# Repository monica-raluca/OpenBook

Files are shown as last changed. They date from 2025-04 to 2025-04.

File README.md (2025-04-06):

# 📚🌟 OpenBook 🌟📚
#### Birladeanu Raluca-Monica 335CA
> An infinite little library, your very own **pocket-sized story companion**.  Read a thousand books, live a thousand lives with OpenBook!~ 🌸
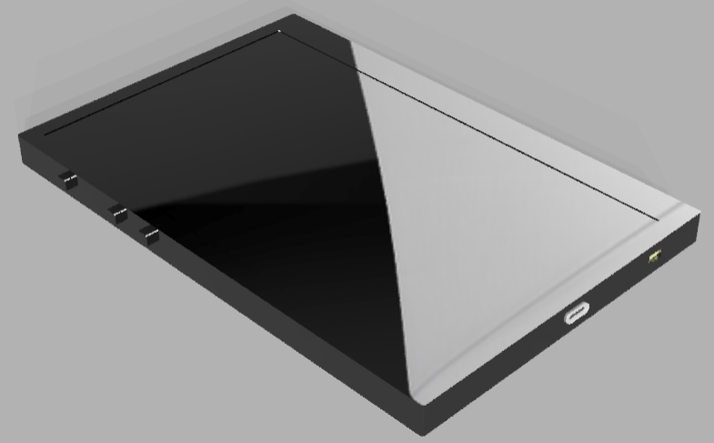
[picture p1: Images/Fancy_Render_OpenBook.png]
OpenBook Image

## Block Diagram
```mermaid
graph TD
  %% Center
  ESP[<span style='color:#e0ccff'><b>ESP32</b></span>]

  %% SPI Devices (Top)
  NOR[<span style='color:#ffcccc'>External NOR Flash</span>]
  EPD[<span style='color:#ffcccc'>E-Paper Display</span>]
  SD[<span style='color:#ffcccc'>SD Card</span>]

  NOR -->|SPI| ESP
  ESP -->|SPI| EPD
  SD -->|SPI| ESP

  %% I2C Devices (Bottom)
  RTC[<span style='color:#cce5ff'>RTC Module</span>]
  ENV[<span style='color:#cce5ff'>Environmental Sensor</span>]
  BCL[<span style='color:#cce5ff'>Battery Charge Level</span>]

  RTC -->|I2C| ESP
  ENV -->|I2C| ESP
  BCL -->|I2C| ESP

  %% Buttons (Left)
  BTN[<span style='color:#d4f4dd'>Buttons</span>]
  BTN --> ESP

  %% USB and Power (Right)
  USB[USB C Connector]
  CHG[Charging Controller]
  REG[Voltage Regulator]
  BATT[Battery]

  ESP -->|USB| USB
  USB --> CHG
  USB --> REG
  BATT --> CHG
  BATT --> REG

```
## Bill of Materials
|Component|Description|Purchase|Datasheet|
|---|---|---|---|
|EAGLE-LTSPICE_CC0402 | Capacitor | https://eu.mouser.com/ProductDetail/KEMET/C0402C475K8PACTU?qs=ulEaXIWI0c9ebKRT3r3htg%3D%3D | https://eu.mouser.com/datasheet/2/447/KEM_C1006_X5R_SMD-3316465.pdf
|ESP32_WROVER_EAGLE-LTSPICE_RR0402 | Resistor | https://eu.mouser.com/ProductDetail/Vishay-Beyschlag/MCS04020D9101BE000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  | https://www.vishay.com/docs/28700/mcx0x0xpre.pdf
|RCL_CPOL-EUCT3528 | Capacitor | https://eu.mouser.com/ProductDetail/Nichicon/LGN2W101MELA25?qs=Fe64Qgzkstf1zMszMsgRoA%3D%3D | https://eu.mouser.com/datasheet/2/293/e_lgn-3082370.pdf
|ADAFRUIT_LEDCHIP-LED0603 | LED | https://eu.mouser.com/ProductDetail/ams-OSRAM/KG-EELP41.22-PHRH-35-A8J8-20-R18?qs=ZcfC38r4Posajg8ZvCDQkg%3D%3D | https://eu.mouser.com/datasheet/2/588/KG_EELP41_22_EN-3572852.pdf
|CPH3225A | Capacitor | https://eu.mouser.com/ProductDetail/Seiko-Semiconductors/CPH3225A?qs=3etwrb1wR%252BhUOph6lAO7eg%3D%3D | https://eu.mouser.com/datasheet/2/360/Seiko_Instruments_MicroBattery_E_20230330_2024Jan_-3561061.pdf
|ESP32_WROVER_SPARKFUN-DISCRETESEMI_MOSFET_PCH-DMG2305UX-7 | Transistor | https://eu.mouser.com/ProductDetail/Diodes-Incorporated/DMG2305UX-7?qs=L1DZKBg7t5F%2FNBHrjfxC%252Bg%3D%3D | https://www.diodes.com/assets/Datasheets/DMG2305UX.pdf
|ESP32_WROVER_AVX---SD0805S020S1R0_AVX_SD0805S020S1R0_0_0AVX_SD0805S020S1R0_0_0 | Diode | https://eu.mouser.com/ProductDetail/ROHM-Semiconductor/SCS310AMC7G?qs=iLKYxzqNS75xiccEgNnX2g%3D%3D | https://fscdn.rohm.com/en/products/databook/datasheet/discrete/sic/sbd/scs310am-e.pdf
|SI1308EDL-T1-GE3 | Transistor | https://eu.mouser.com/ProductDetail/Vishay-Semiconductors/SI1308EDL-T1-GE3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 | https://www.vishay.com/docs/63399/si1308edl.pdf
|ESP32C6_VARISTORCN1812 | Varistor | https://eu.mouser.com/ProductDetail/Schurter/PFMF.050.2?qs=1auRipcfynCums5v1iucSA%3D%3D | https://eu.mouser.com/datasheet/2/358/typ_PFMF-1275918.pdf
|ESP32_WROVER_BME680_BME680 | Integrated Environmental Unit | https://eu.mouser.com/ProductDetail/M5Stack/U001-C?qs=e8oIoAS2J1R2mB7ZY1%252BSZg%3D%3D | https://docs.m5stack.com/en/unit/envIII
|ESP32-C6-WROOM-1-N8 | MicroController | https://eu.mouser.com/ProductDetail/Espressif-Systems/ESP32-C6?qs=Imq1NPwxi75noDtUpuVuWw%3D%3D | https://eu.mouser.com/datasheet/2/891/esp32_c6_datasheet_en-3304070.pdf
| 744043680IND_4828-WE-TPC_WRE | Inductor | https://eu.mouser.com/ProductDetail/Wurth-Elektronik/744043680?qs=PGXP4M47uW6VkZq%252BkzjrHA%3D%3D | https://www.we-online.com/components/products/datasheet/744043680.pdf
|SI1308EDL-T1-GE3 | Transistor | https://eu.mouser.com/ProductDetail/Vishay-Semiconductors/SI1308EDL-T1-GE3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 | https://www.vishay.com/docs/63399/si1308edl.pdf
| BD5229G-TR | Voltage Detector | https://eu.mouser.com/ProductDetail/ROHM-Semiconductor/BD5229G-TR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 | https://fscdn.rohm.com/en/products/databook/datasheet/ic/power/voltage_detector/bd52xxg-e.pdf
|DS3231SN# | RTC Module | https://eu.mouser.com/ProductDetail/Analog-Devices-Maxim-Integrated/DS3231SN?qs=1eQvB6Dk1vhUlr8%2FOrV0Fw%3D%3D | https://eu.mouser.com/datasheet/2/609/DS3231-3421123.pdf
|USBLC6-2SC6Y | ESD Protection | https://eu.mouser.com/ProductDetail/STMicroelectronics/USBLC6-2SC6Y?qs=gNDSiZmRJS%2FOgDexvXkdow%3D%3D | https://eu.mouser.com/datasheet/2/389/usblc6_2sc6y-1852505.pdf
|W25Q512JVEIQ | Flash Memory | https://eu.mouser.com/ProductDetail/Winbond/W25Q512JVEIQ?qs=l7cgNqFNU1jw6svr3at6tA%3D%3D | https://eu.mouser.com/datasheet/2/949/Winbond_W25Q512JV_Datasheet-3240039.pdf
|SAMACSYS_PARTS_USB4110-GF-A | USB Connector | https://eu.mouser.com/ProductDetail/GCT/USB4110-GF-A?qs=KUoIvG%2F9IlYiZvIXQjyJeA%3D%3D | https://eu.mouser.com/datasheet/2/837/GCT_USB4110_Product_Drawing___20k_cycles-3455479.pdf
|FH34SRJ | E-Paper Display Header | https://eu.mouser.com/ProductDetail/Hirose-Connector/FH34SRJ-7S-0.5SH50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 | https://eu.mouser.com/datasheet/2/185/FH34SRJ_7S_0_5SH_50__CL0580_1200_0_50_2DDrawing_00-1615127.pdf
|MAX17048G+T10 | Battery Management | https://eu.mouser.com/ProductDetail/Analog-Devices-Maxim-Integrated/MAX17048G%2bT10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 | https://eu.mouser.com/datasheet/2/609/MAX17048_MAX17049-3469099.pdf
|MCP73831 | Battery Controller | https://eu.mouser.com/ProductDetail/Microchip-Technology/MCP73831T-2ATI-MC?qs=yUQqVecv4qs9k7ug0bEXiw%3D%3D | https://eu.mouser.com/datasheet/2/268/MCP73831_Family_Data_Sheet_DS20001984H-3441711.pdf
|112A-TAAR-R03_ATTEND | SD Card Mount | https://store.comet.srl.ro/Catalogue/Product/43497/ | https://store.comet.srl.ro/Catalogue/Product/43497/
|XC6220A331MR-G | LDO Voltage Regulator | https://eu.mouser.com/ProductDetail/Torex-Semiconductor/XC6220A331MR-G?qs=AsjdqWjXhJ8ZSWznL1J0gg%3D%3D | https://eu.mouser.com/datasheet/2/760/xc6220-3371556.pdf

## Hardware components
- ESP32-C6-WROOM-1-N8 Microcontroller

### Communication interfaces

| Communication interface | Connected Components |
|---|---|
| I2C | RTC, BME688, Battery Level |
| SPI | SD Card, E-Paper Display, NOR Flash |
| USB | USB C Connector / Power |

### ESP32-C6-WROOM-1-N8 Pin Mapping

| ESP32 Pin | Signal | Purpose |
|---|---|---|
| IO0 | INT_RTC | RTC communication |
| IO1 | 32KHZ | RTC communication |
| IO2 | MISO | SD Card, NOR Flash |
| IO3 | EPD_BUSY | EPD status |
| IO4 | SS_SD | SD Card |
| IO5 | EPD_DC | EPD Data/Command |
| IO6 | SCK  | BME688, SD Card, NOR Flash |
| IO7 | MOSI | SD Card, NOR Flash, EPD |
| IO8 | GPIO8 | SD card select |
| IO9 | IO/BOOT | Boot button |
| IO10 | EPD_CS | EPD chip select|
| IO11 | FLASH_CS | NOR Flash chip select |
| IO12 | USB_D-| USB communication |
| IO13 | USB_D+ | USB communication |
| IO15 | IO/CHANGE | Button change |
| IO16 | TX | Transmit |
| IO17 | RX | Receive |
| IO18 | RTC_RST | RTC reset |
| IO19 | I2C_PW | BME688 power management |
| IO20 | EPD_3V3_C | EPD |
| IO21 | SDA | RTC, BME688, Battery Level (I2C data) |
| IO22 | SCL | RTC, BME688, Battery Level (I2C clock) |
| IO23 | EPD_RST | EPD reset |

- Real-Time Clock Module (RTC)
  - A DS3231SN RTC module
  - It communicates through I2C with the microcontroller
  - Pin connections:
      - SCL -> IO22
      - SDA -> IO21
      - RTC_RST -> IO18
      - 32KHZ -> IO1
      - INT_RTC -> IO0
- SD Card
  - It communicates through SPI
  - Pin connections:
    - MISO - IO2
    - SCK - IO6
    - MOSI - IO7
    - SS_SD - IO4
- E-Paper Display (EPD)
  - It communicates through SPI
  - Pin connections:
    - EPD_CS -> IO10
    - EPD_DC -> IO5
    - EPD_RST -> IO23
    - EPD_BUSY -> IO3
    - MOSI, SCK -> shared with SD
- Environmental Sensor
  - BME688 sensor
  - It communicates through I2C
  - Pin connections:
      - SCL -> IO22
      - SDA -> IO21
- Li-Po Battery Charging Controller
  - Battery Charge Level
    - It communicates through I2C
    - Pin connections:
        - SCL -> IO22
        - SDA -> IO21
- LDO Voltage Regulator
  - Lowers the 5V to 3.3V for the microcontroller and the attached modules
- SPI ESD Protection Lines
- NOR Flash 64MB
  - It communicates through SPI
  - Pin connections:
    - FLASH_CS -> IO11
    - SCK, MOSI, MISO
- USB
  - USB_D- -> IO12
  - USB_D+ -> IO13
- Buttons for user input
  - RESET -> EN
  - IO/BOOT -> IO9
  - IO/CHANGE -> IO15
- Qwiic / Stemma QT Connector
  - It communicates through I2C
  - SCL, SDA

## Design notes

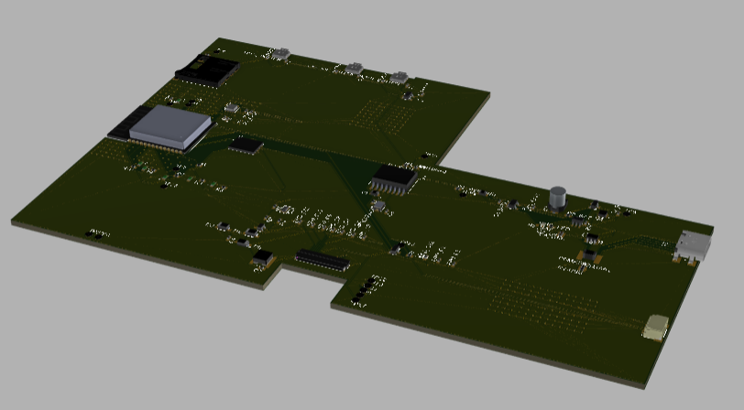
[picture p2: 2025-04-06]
Images/Side_view_Board.png

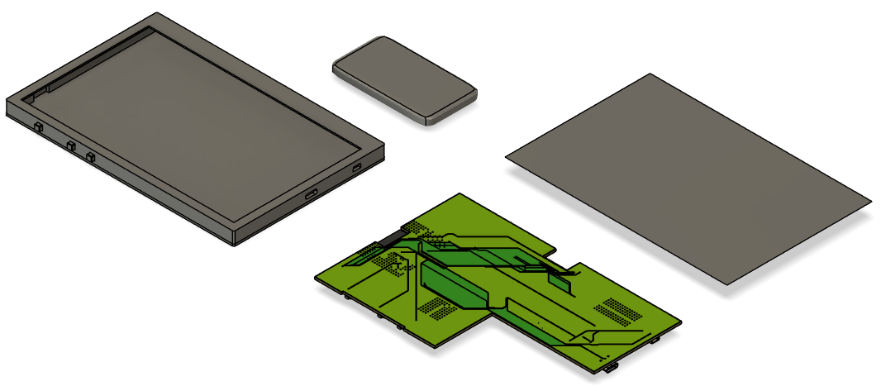
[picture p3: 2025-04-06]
Images/Animation_View_OpenBook.png

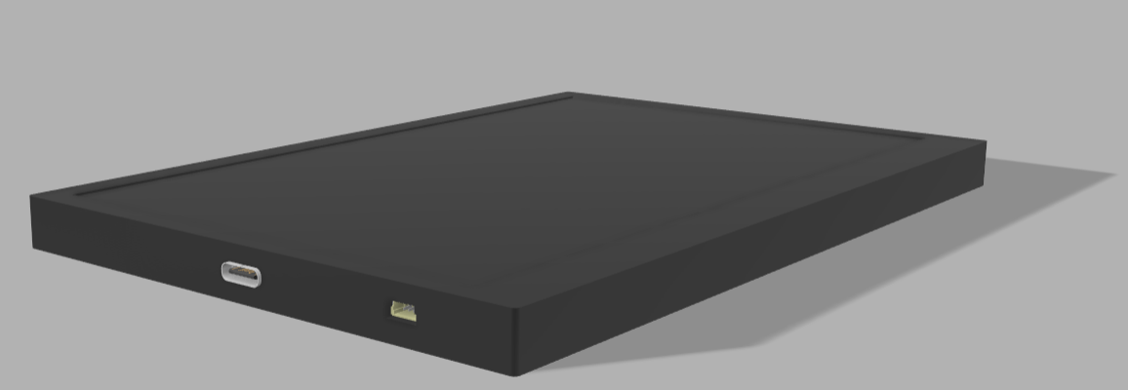
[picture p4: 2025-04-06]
Images/Side_view_OpenBook.png

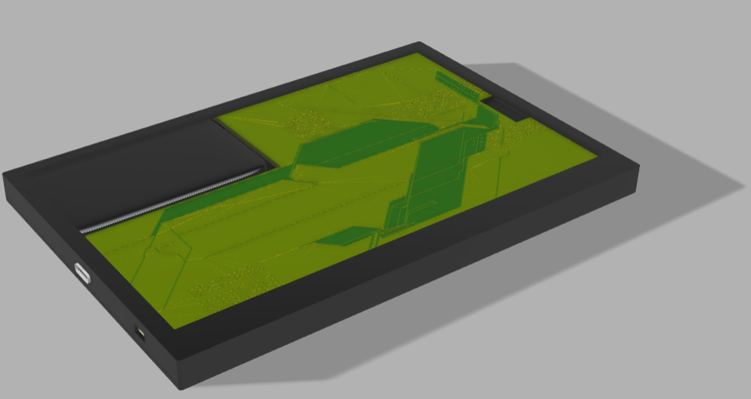
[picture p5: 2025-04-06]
Images/Interior_OpenBook.png

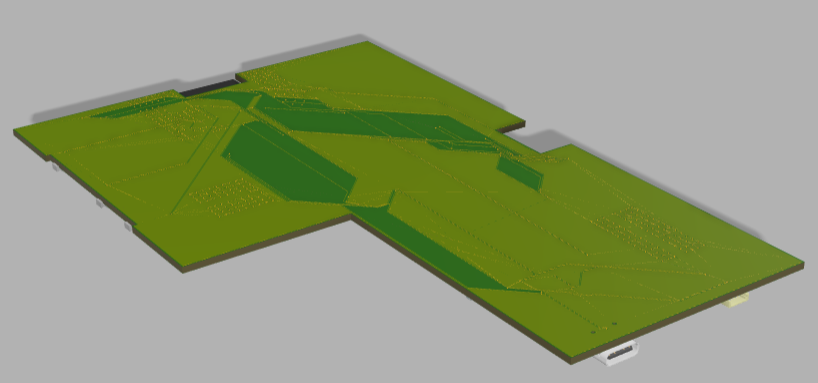
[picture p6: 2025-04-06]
Images/Second_Side_Board.png

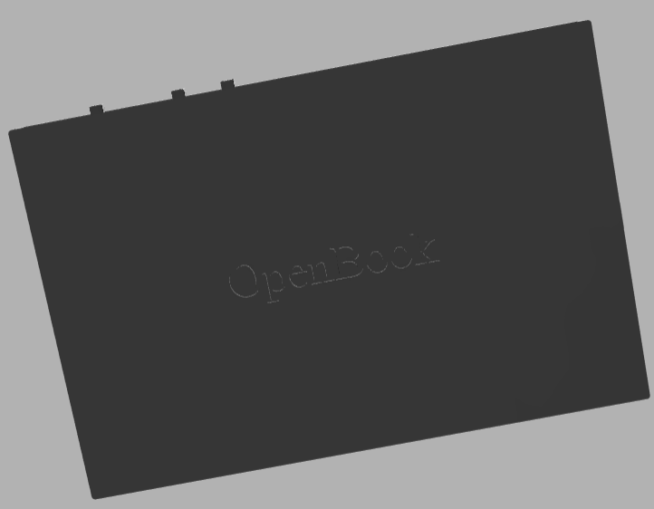
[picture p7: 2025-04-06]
Images/Back_view_OpenBook.png

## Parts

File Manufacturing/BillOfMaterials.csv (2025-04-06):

Qty | Value | Device | Package | Parts | Description | ARROW_PART_NUMBER | ARROW_PRICE-STOCK | AVAILABILITY | CHECK_PRICES | COPYRIGHT | DESCRIPTION | HEIGHT | MANUFACTURER_NAME | MANUFACTURER_PART_NUMBER | MF | MFR_NAME | MOUSER_PART_NUMBER | MOUSER_PRICE-STOCK | MOUSER_TESTING_PART_NUMBER | MOUSER_TESTING_PRICE-STOCK | MP | PACKAGE | POPULARITY | PRICE | PROD_ID | PURCHASE-URL | SNAPEDA_LINK | SPICEPREFIX | VALUE
1 |  | ADAFRUIT_LEDCHIP-LED0603 | ADAFRUIT_CHIP-LED0603 | CHG_LED | LED
1 |  | SJ | SJ | SJ1 | SMD solder JUMPER |  |  |  |  |  |  |  |  |  |  |  |  |  |  |  |  |  | 3
1 | 0.1uF/50V | EAGLE-LTSPICE_CC0402 | EAGLE-LTSPICE_C0402 | EPD_C5 | CAPACITOR, European symbol
1 | 0.47 | ESP32_WROVER_EAGLE-LTSPICE_RR0402 | ESP32_WROVER_EAGLE-LTSPICE_R0402 | R3 | RESISTOR, European symbol
1 | 100K | ESP32_WROVER_EAGLE-LTSPICE_RR0402 | ESP32_WROVER_EAGLE-LTSPICE_R0402 | R1_PWRUSB | RESISTOR, European symbol
8 | 100nF | EAGLE-LTSPICE_CC0402 | EAGLE-LTSPICE_C0402 | C1, C2, C4_USB, C6, C8, C9, C10, C_DELAY | CAPACITOR, European symbol
1 | 100uF | RCL_CPOL-EUCT3528 | RCL_CT3528 | C3 | POLARIZED CAPACITOR, European symbol |  |  |  |  |  |  |  |  |  |  |  |  |  |  |  |  |  | 0 |  |  |  |  | C
16 | 10K | ESP32_WROVER_EAGLE-LTSPICE_RR0402 | ESP32_WROVER_EAGLE-LTSPICE_R0402 | R1, R1_PINH, R1_PINH1, R2_PINH, R2_PINH1, R4, R5, R6, R7, R8, R9, R10, R_BOOT, R_CHANGE, R_CL1, R_RESET | RESISTOR, European symbol
1 | 10uF | EAGLE-LTSPICE_CC0402 | EAGLE-LTSPICE_C0402 | C7 | CAPACITOR, European symbol
1 | 112A-TAAR-R03_ATTEND | 112A-TAAR-R03_ATTEND | 112ATAARR03ATTEND | J4 | Micro SD Card Socket, Push-Push Type, Top Mount, SMT, H=1.83mm, 10u |  |  |  |  |  | Micro SD Card Socket | Push-Push Type | Top Mount | SMT | H=1.83mm | 10u | 1.9mm | ATTEND | 112A-TAAR-R03 ATTEND
1 | 15 | ESP32_WROVER_EAGLE-LTSPICE_RR0402 | ESP32_WROVER_EAGLE-LTSPICE_R0402 | R_CAPACITOR | RESISTOR, European symbol
1 | 1uF | EAGLE-LTSPICE_CC0402 | EAGLE-LTSPICE_C0402 | C5 | CAPACITOR, European symbol
9 | 1uF/50V | EAGLE-LTSPICE_CC0402 | EAGLE-LTSPICE_C0402 | EPD_C1, EPD_C2, EPD_C6, EPD_C7, EPD_C8, EPD_C9, EPD_C10, EPD_C11, EPD_C12 | CAPACITOR, European symbol
1 | 2.2 | ESP32_WROVER_EAGLE-LTSPICE_RR0402 | ESP32_WROVER_EAGLE-LTSPICE_R0402 | R2 | RESISTOR, European symbol
1 | 200 | ESP32_WROVER_EAGLE-LTSPICE_RR0402 | ESP32_WROVER_EAGLE-LTSPICE_R0402 | R1_BAT | RESISTOR, European symbol
2 | 20V/4.2A/52mO/1.4W | ESP32_WROVER_SPARKFUN-DISCRETESEMI_MOSFET_PCH-DMG2305UX-7 | ESP32_WROVER_SPARKFUN-DISCRETESEMI_SOT23-3 | Q1, Q2 | P-channel MOSFETs
1 | 2K | ESP32_WROVER_EAGLE-LTSPICE_RR0402 | ESP32_WROVER_EAGLE-LTSPICE_R0402 | R2_BAT | RESISTOR, European symbol
5 | 4.7uF | EAGLE-LTSPICE_CC0402 | EAGLE-LTSPICE_C0402 | C1_BAT, C1_BAT1, C1_BAT2, C2_BAT, C5_USB | CAPACITOR, European symbol
1 | 4.7uF/25V | EAGLE-LTSPICE_CC0402 | EAGLE-LTSPICE_C0402 | C4 | CAPACITOR, European symbol
2 | 5k1 | ESP32_WROVER_EAGLE-LTSPICE_RR0402 | ESP32_WROVER_EAGLE-LTSPICE_R0402 | R2-USB, R2-USB1 | RESISTOR, European symbol
1 | 68uH | 744043680IND_4828-WE-TPC_WRE | IND_4828-WE-TPC_WRE | L1 |  |  |  |  |  | Copyright (C) 2024 Ultra Librarian. All rights reserved. |  |  |  | 744043680 |  | Wurth Electronics
1 | BD5229G-TR | BD5229G-TR | SOT95P280X125-5N | IC1 | Voltage Detector with Adjustable Delay Time: CMOS processes are utilized to develop high precision, low current consumption CMOS reset ICs that allow arbitrary setting of the delay time. The extensive lineup includes both Nch Open Drain and CMOS output types in a wide range of detection voltages (from 2.3V to 6.0V, in 0.1V steps), enabling selection of the ideal solution based on customer requirements. In addition, the entire series is of course both lead-free and RoHS-compliant. |  |  |  |  |  | Voltage Detector with Adjustable Delay Time: CMOS processes are utilized to develop high precision | low current consumption CMOS reset ICs that allow arbitrary setting of the delay time. The extensive lineup includes both Nch Open Drain and CMOS output types in a wide range of detection voltages (from 2.3V to 6.0V | in 0.1V steps) | enabling selection of the ideal solution based on customer requirements. In addition | the entire series is of course both lead-free and RoHS-compliant. | 1.25mm | ROHM Semiconductor | BD5229G-TR |  |  | 755-BD5229G-TR | https://www.mouser.co.uk/ProductDetail/ROHM-Semiconductor/BD5229G-TR?qs=4kLU8WoGk0vvnhrrYwdszw%3D%3D
1 | BME688 | ESP32_WROVER_BME680_BME680 | ESP32_WROVER_BME680_PSON80P300X300X100-8N | SENSOR2 | Integrated Environmental Unit |  |  | Unavailable |  |  | Integrated Environmental Unit |  |  |  | Bosch Sensortec |  |  |  |  |  | BME680 | LGA-8 Bosch Tools |  | None
3 | BUTTON_CUSYOMV1MYBUTTON | BUTTON_CUSYOMV1MYBUTTON | MYBUTTON | BOOT_BUTTON, CHANGE_BUTTON, RESET_BUTTON
1 | CPH3225A | CPH3225A | CAPCP3225X100N | C10_SUPERCAP | Cap 0.011F 3.3V 1210 Flat Check availability |  |  | Not in stock | https://www.snapeda.com/parts/CPH3225A/Seiko+Instruments/view-part/?ref=eda |  | 11 mF (EDLC) Supercapacitor 3.3 V 1210 (3225 Metric) - - |  |  |  | Seiko Instruments |  |  |  |  |  | CPH3225A | 1210 Seiko |  | None |  | https://www.snapeda.com/api/url_track_click_mouser/?unipart_id=562593&manufacturer=Seiko Instruments&part_name=CPH3225A&search_term=None | https://www.snapeda.com/parts/CPH3225A/Seiko+Instruments/view-part/?ref=snap
1 | DS3231SN# | DS3231SN# | SOIC127P1032X265-16N | U3 | Real Time Clock Serial 16-Pin SOIC W T/R Check availability |  |  | In Stock | https://www.snapeda.com/parts/DS3231SN%23/Analog+Devices/view-part/?ref=eda |  | Extremely Accurate I²C-Integrated RTC/TCXO/Crystal |  |  |  | Analog Devices |  |  |  |  |  | DS3231SN# | SOIC-16 Maxim |  | None |  | https://www.snapeda.com/api/url_track_click_mouser/?unipart_id=99048&manufacturer=Analog Devices&part_name=DS3231SN#&search_term=None | https://www.snapeda.com/parts/DS3231SN%23/Analog+Devices/view-part/?ref=snap
1 | ESP32-C6-WROOM-1-N8 | ESP32-C6-WROOM-1-N8 | XCVR_ESP32-C6-WROOM-1-N8 | U2 | Check availability |  |  | In Stock | https://www.snapeda.com/parts/ESP32-C6-WROOM-1-N8/Espressif+Systems/view-part/?ref=eda |  | Multiprotocol Modules ESP32-C6 module | Wi-Fi 6 in 2.4 GHz band | Bluetooth 5 | Zigbee 3.0 and Thread. ESP34-WROOM Compatible - ENGINEERING SAMPLE |  |  |  | Espressif Systems |  |  |  |  |  | ESP32-C6-WROOM-1-N8 | None |  | None
1 | ESP32C6_VARISTORCN1812 | ESP32C6_VARISTORCN1812 | ESP32C6_VARISTOR_CT/CN1812 | PFMF.050.1 | VARISTOR |  |  |  |  |  |  |  |  |  |  |  |  |  |  |  |  |  | 0
2 | ESP32_WROVER_AVX---SD0805S020S1R0_AVX_SD0805S020S1R0_0_0AVX_SD0805S020S1R0_0_0 | ESP32_WROVER_AVX---SD0805S020S1R0_AVX_SD0805S020S1R0_0_0AVX_SD0805S020S1R0_0_0 | ESP32_WROVER_AVX---SD0805S020S1R0_AVX_SD0805S020S1R0_0 | D2, D7 | Schottky Barrier Rectifier Diode
1 | FH34SRJ-24S-0.5SH_99_ | FH34SRJ-24S-0.5SH_99_ | FH34SRJ24S05SH99 | J1 | (0.50mm) Surface Mount, Right Angle |  |  |  |  |  | 24 Position FFC | FPC Connector Contacts | (0.50mm) Surface Mount | Right Angle | 1.1mm | Hirose | FH34SRJ-24S-0.5SH(99) |  |  | 798-FH34SRJ24S05SH99 | https://www.mouser.co.uk/ProductDetail/Hirose-Connector/FH34SRJ-24S-0.5SH99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
1 | MAX17048G+T10 | MAX17048G+T10 | SON50P200X200X80-9N | U4 | Check availability |  |  | In Stock | https://www.snapeda.com/parts/MAX17048G+T10/Analog+Devices/view-part/?ref=eda |  | 3µA 1-Cell/2-Cell Fuel Gauge with ModelGauge |  |  |  | Analog Devices |  |  |  |  |  | MAX17048G+T10 | TDFN-8 Maxim |  | None |  | https://www.snapeda.com/api/url_track_click_mouser/?unipart_id=329239&manufacturer=Analog Devices&part_name=MAX17048G+T10&search_term=None | https://www.snapeda.com/parts/MAX17048G+T10/Analog+Devices/view-part/?ref=snap
3 | MBR0530SOD3716X135 | MBR0530SOD3716X135 | SOD3716X135N | D3, D4, D5 | ON SEMICONDUCTOR - MBR0530 - DIODE, SCHOTTKY, 0.5A, 30V, SOD-123
1 | MCP73831 | ESP32_WROVER_SPARKFUN-IC-POWER_MCP73831 | ESP32_WROVER_SPARKFUN-IC-POWER_SOT23-5 | U5 | MCP73831T Li-Ion, Li-Pol Controller |  |  |  |  |  |  |  |  |  |  |  |  |  |  |  |  |  |  |  | IC-09995
6 | PGB1010603MRDIOC | PGB1010603MRDIOC | DIOC1608X36N | D6, D8, D9, D10, D11, D12 | Check availability
1 | QWIIC_RIGHT_ANGLE | QWIIC_CONNECTORJS-1MM | JST04_1MM_RA | J3 | SparkFun I2C Standard Qwiic Connector |  |  |  |  |  |  |  |  |  |  |  |  |  |  |  |  |  |  |  | CONN-13694 |  |  |  | QWIIC_RIGHT_ANGLE
1 | SAMACSYS_PARTS_USB4110-GF-A | SAMACSYS_PARTS_USB4110-GF-A | SAMACSYS_PARTS_USB4110GFA | J2 | CONN USB 2.0 TYPE-C R/A SMT |  |  |  |  |  | CONN USB 2.0 TYPE-C R/A SMT | 3.26mm | GCT (GLOBAL CONNECTOR TECHNOLOGY) | USB4110-GF-A |  |  | 640-USB4110-GF-A | https://www.mouser.co.uk/ProductDetail/GCT/USB4110-GF-A?qs=KUoIvG%2F9IlYiZvIXQjyJeA%3D%3D
1 | SI1308EDL-T1-GE3 | SI1308EDL-T1-GE3 | SOT65P210X110-3N | Q3 | MOSFET N-Ch 30V 1.5A TrenchFET SC70 Vishay Si1308EDL-T1-GE3 N-channel MOSFET Transistor, 1.5 A, 30 V, 3-Pin SC-70 |  |  | In Stock | https://www.snapeda.com/parts/SI1308EDL-T1-GE3/Vishay+Siliconix/view-part/?ref=eda |  | Si1308EDL-T1-GE3 N-channel MOSFET Transistor | 1.5 A | 30 V | 3-Pin SC-70 | Siliconix / Vishay SI1308EDL-T1-GE3 |  |  |  | Vishay Siliconix |  |  |  |  |  | SI1308EDL-T1-GE3 | SOT-323 Vishay Semiconductor |  | None |  | https://www.snapeda.com/api/url_track_click_mouser/?unipart_id=274603&manufacturer=Vishay Siliconix&part_name=SI1308EDL-T1-GE3&search_term=None
17 | TPTP20R | TPTP20R | TP20R | TP1, TP2, TP3, TP4, TP5, TP6, TP7, TP8, TP9, TP10, TP11, TP12, TP13, TP14, TP15, TP16, TP17 | Test pad
1 | USBLC6-2SC6Y | USBLC6-2SC6Y | SOT95P280X145-6N | D1 | Low Cap. ESD Protection Auto SOT-23-6 STMicroelectronics USBLC6-2SC6Y, Dual Uni-Directional TVS Diode Array, 6-Pin SOT-23 |  |  | In Stock | https://www.snapeda.com/parts/USBLC6-2SC6Y/STMicroelectronics/view-part/?ref=eda |  | 17V Clamp 5A (8/20µs) Ipp Tvs Diode Surface Mount SOT-23-6 |  |  |  | STMicroelectronics |  |  |  |  |  | USBLC6-2SC6Y | SOT-23-6 STMicroelectronics |  | None |  |  | https://www.snapeda.com/parts/USBLC6-2SC6Y/STMicroelectronics/view-part/?ref=snap
1 | W25Q512JVEIQ | W25Q512JVEIQ | SON127P600X800X80-9N | U1 | Check availability |  |  | In Stock | https://www.snapeda.com/parts/W25Q512JVEIQ/Winbond+Electronics/view-part/?ref=eda |  | FLASH - NOR Memory IC 512Mb (64M x 8) SPI - Quad I/O 133 MHz 8-WSON (8x6) |  |  |  | Winbond Electronics |  |  |  |  |  | W25Q512JVEIQ | Package |  | None |  |  | https://www.snapeda.com/parts/W25Q512JVEIQ/Winbond+Electronics/view-part/?ref=snap
1 | XC6220A331MR-G | XC6220A331MR-G | SOT95P280X120-5N | IC4 | LDO Voltage Regulators |  |  |  |  |  | LDO Voltage Regulators | 1.2mm | Torex | XC6220A331MR-G |  |  | 865-XC6220A331MR-G | https://www.mouser.co.uk/ProductDetail/Torex-Semiconductor/XC6220A331MR-G?qs=AsjdqWjXhJ8ZSWznL1J0gg%3D%3D

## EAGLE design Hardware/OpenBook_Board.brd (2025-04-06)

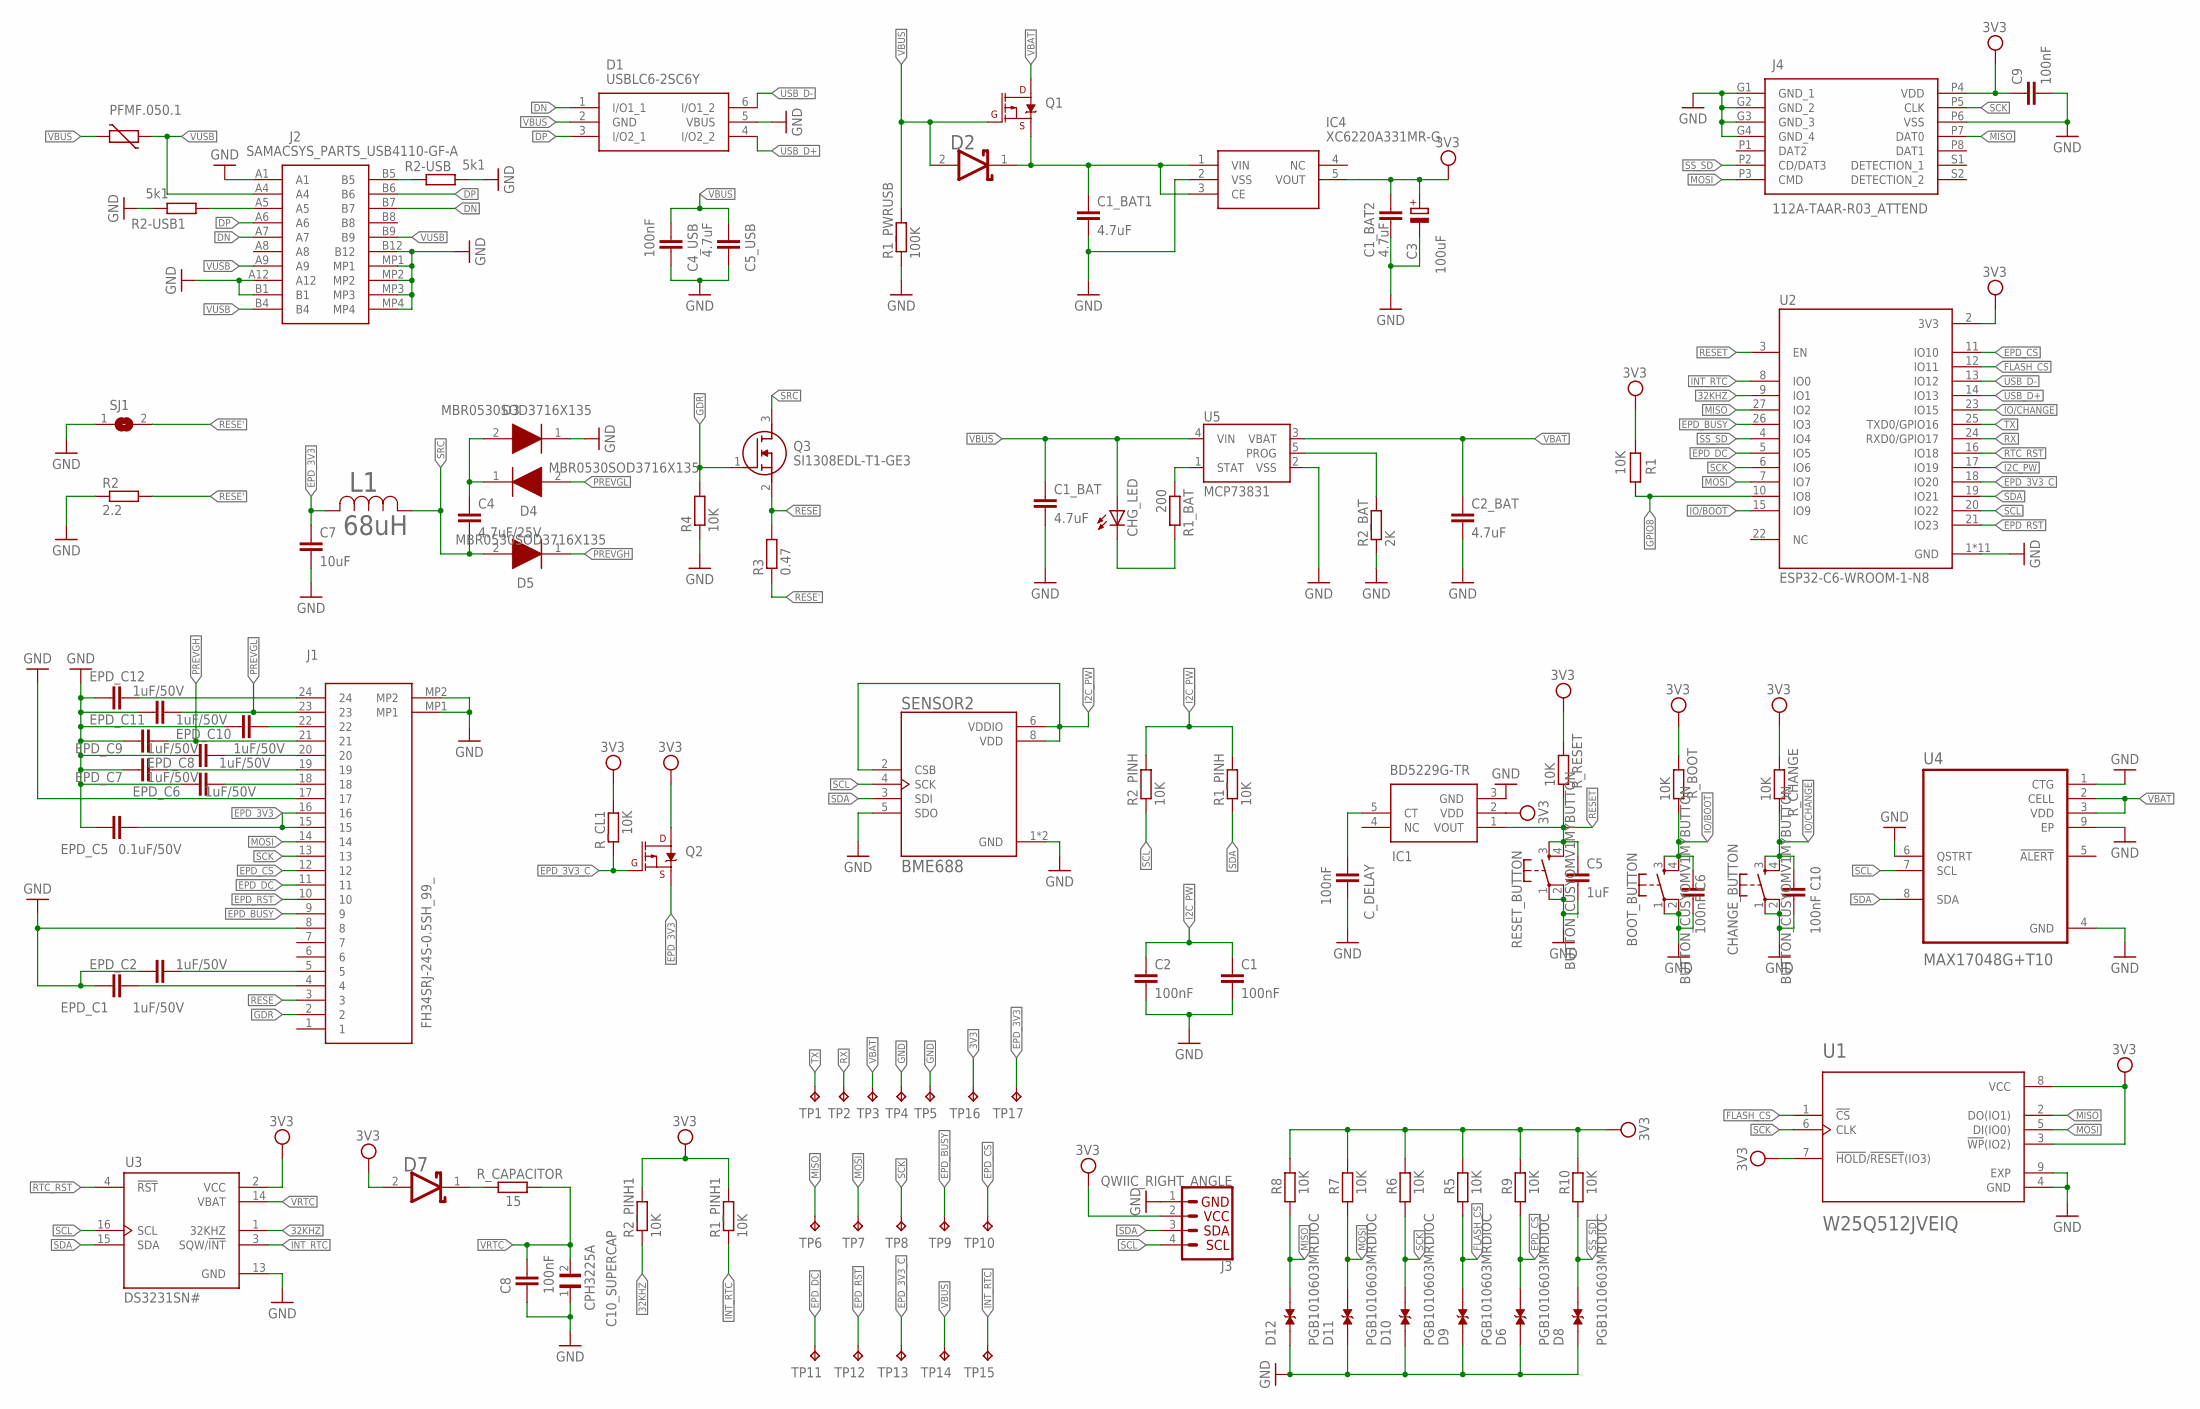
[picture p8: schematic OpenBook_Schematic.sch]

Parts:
BOOT_BUTTON: BUTTON_CUSYOMV1MYBUTTON; MYBUTTON
C1, C2, C4_USB, C6, C8, C9, C10: 100nF; EAGLE-LTSPICE_C0402
C1_BAT, C1_BAT1, C1_BAT2, C2_BAT, C5_USB: 4.7uF; EAGLE-LTSPICE_C0402
C3: 100uF; RCL_CT3528
C4: 4.7uF/25V; EAGLE-LTSPICE_C0402
C5: 1uF; EAGLE-LTSPICE_C0402
C7: 10uF; EAGLE-LTSPICE_C0402
C10_SUPERCAP: CPH3225A; CAPCP3225X100N
CHANGE_BUTTON: BUTTON_CUSYOMV1MYBUTTON; MYBUTTON
CHG_LED: ADAFRUIT_LEDCHIP-LED0603; ADAFRUIT_CHIP-LED0603
C_DELAY: 100nF; EAGLE-LTSPICE_C0402
D1: USBLC6-2SC6Y; SOT95P280X145-6N
D2, D7: ESP32_WROVER_AVX---SD0805S020S1R0_AVX_SD0805S020S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; ESP32_WROVER_AVX---SD0805S020S1R0_AVX_SD0805S020S1R0_0
D3, D4, D5: MBR0530SOD3716X135; SOD3716X135N
D6, D8, D9, D10, D11, D12: PGB1010603MRDIOC; DIOC1608X36N
EPD_C1, EPD_C2, EPD_C6, EPD_C7, EPD_C8, EPD_C9, EPD_C10, EPD_C11, EPD_C12: 1uF/50V; EAGLE-LTSPICE_C0402
EPD_C5: 0.1uF/50V; EAGLE-LTSPICE_C0402
IC1: BD5229G-TR; SOT95P280X125-5N
IC4: XC6220A331MR-G; SOT95P280X120-5N
J1: FH34SRJ-24S-0.5SH_99_; FH34SRJ24S05SH99
J2: SAMACSYS_PARTS_USB4110-GF-A; SAMACSYS_PARTS_USB4110GFA
J3: QWIIC_RIGHT_ANGLE; JST04_1MM_RA
J4: 112A-TAAR-R03_ATTEND; 112ATAARR03ATTEND
L1: 68uH; IND_4828-WE-TPC_WRE
PFMF.050.1: ESP32C6_VARISTORCN1812; ESP32C6_VARISTOR_CT/CN1812
Q1, Q2: 20V/4.2A/52mΩ/1.4W; ESP32_WROVER_SPARKFUN-DISCRETESEMI_SOT23-3
Q3: SI1308EDL-T1-GE3; SOT65P210X110-3N
R1, R1_PINH, R1_PINH1, R2_PINH, R2_PINH1, R4, R5, R6, R7, R8, R9, R10: 10K; ESP32_WROVER_EAGLE-LTSPICE_R0402
R1_BAT: 200; ESP32_WROVER_EAGLE-LTSPICE_R0402
R1_PWRUSB: 100K; ESP32_WROVER_EAGLE-LTSPICE_R0402
R2: 2.2; ESP32_WROVER_EAGLE-LTSPICE_R0402
R2-USB, R2-USB1: 5k1; ESP32_WROVER_EAGLE-LTSPICE_R0402
R2_BAT: 2K; ESP32_WROVER_EAGLE-LTSPICE_R0402
R3: 0.47; ESP32_WROVER_EAGLE-LTSPICE_R0402
RESET_BUTTON: BUTTON_CUSYOMV1MYBUTTON; MYBUTTON
R_BOOT: 10K; ESP32_WROVER_EAGLE-LTSPICE_R0402
R_CAPACITOR: 15; ESP32_WROVER_EAGLE-LTSPICE_R0402
R_CHANGE: 10K; ESP32_WROVER_EAGLE-LTSPICE_R0402
R_CL1: 10K; ESP32_WROVER_EAGLE-LTSPICE_R0402
R_RESET: 10K; ESP32_WROVER_EAGLE-LTSPICE_R0402
SENSOR2: BME688; ESP32_WROVER_BME680_PSON80P300X300X100-8N
SJ1: SJ
TP1, TP2, TP3, TP4, TP5, TP6, TP7, TP8, TP9, TP10, TP11, TP12, TP13, TP14, TP15, TP16, TP17: TPTP20R; TP20R
U1: W25Q512JVEIQ; SON127P600X800X80-9N
U2: ESP32-C6-WROOM-1-N8; XCVR_ESP32-C6-WROOM-1-N8
U3: DS3231SN#; SOIC127P1032X265-16N
U4: MAX17048G+T10; SON50P200X200X80-9N
U5: MCP73831; ESP32_WROVER_SPARKFUN-IC-POWER_SOT23-5

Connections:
3V3: C1_BAT2.1, C3.+, C9.1, D7.2 (ANODE), IC1.2 (VDD), IC4.5 (VOUT), J3.2, J4.P4 (VDD), Q2.3 (D), R1.2, R1_PINH1.2, R2_PINH1.2, R5.2, R6.2, R7.2, R8.2, R9.2, R10.2, R_BOOT.1, R_CHANGE.1, R_CL1.2, R_RESET.1, TP16.TP, U1.3 (!WP!(IO2)), U1.7 (!HOLD!/!RESET!(IO3)), U1.8 (VCC), U2.2 (3V3), U3.2 (VCC)
32KHZ: R2_PINH1.1, U2.9 (IO1), U3.1 (32KHZ)
DN: D1.1 (I/O1_1), J2.A7, J2.B7
DP: D1.3 (I/O2_1), J2.A6, J2.B6
EPD_3V3: C7.1, EPD_C5.1, J1.15, J1.16, L1.2, Q2.2 (S), TP17.TP
EPD_3V3_C: Q2.1 (G), R_CL1.1, TP13.TP, U2.18 (IO20)
EPD_BUSY: J1.9, TP9.TP, U2.26 (IO3)
EPD_CS: D6.2, J1.12, R9.1, TP10.TP, U2.11 (IO10)
EPD_DC: J1.11, TP11.TP, U2.5 (IO5)
EPD_RST: J1.10, TP12.TP, U2.21 (IO23)
FLASH_CS: D9.2, R5.1, U1.1 (!CS), U2.12 (IO11)
GDR: J1.2, Q3.1 (G), R4.2
GND: BOOT_BUTTON.1, BOOT_BUTTON.2, C1.2, C1_BAT.2, C1_BAT1.2, C1_BAT2.2, C2.2, C2_BAT.2, C3.-, C4_USB.2, C5.2, C5_USB.2, C6.2, C7.2, C8.2, C9.2, C10.2, C10_SUPERCAP.1, CHANGE_BUTTON.1, CHANGE_BUTTON.2, C_DELAY.2, D1.5 (VBUS), D3.1 (K), D6.1, D8.1, D9.1, D10.1, D11.1, D12.1, EPD_C1.2, EPD_C2.2, EPD_C5.2, EPD_C6.2, EPD_C7.2, EPD_C8.2, EPD_C9.2, EPD_C10.2, EPD_C11.2, EPD_C12.2, IC1.3 (GND), IC4.2 (VSS), J1.8, J1.17, J1.MP1, J1.MP2, J2.A1, J2.A12, J2.B1, J2.B12, J2.MP1, J2.MP2, J2.MP3, J2.MP4, J3.1, J4.G1 (GND_1), J4.G2 (GND_2), J4.G3 (GND_3), J4.G4 (GND_4), J4.P6 (VSS), R1_PWRUSB.1, R2.1, R2-USB.2, R2-USB1.1, R2_BAT.1, R4.1, RESET_BUTTON.1, RESET_BUTTON.2, SENSOR2.1 (GND), SENSOR2.5 (SDO), SENSOR2.7 (GND), SJ1.1, TP4.TP, TP5.TP, U1.4 (GND), U1.9 (EXP), U2.1 (GND), U2.28 (GND), U2.29_1 (GND), U2.29_2 (GND), U2.29_3 (GND), U2.29_4 (GND), U2.29_5 (GND), U2.29_6 (GND), U2.29_7 (GND), U2.29_8 (GND), U2.29_9 (GND), U3.13 (GND), U4.1 (CTG), U4.4 (GND), U4.6 (QSTRT), U4.9 (EP), U5.2 (VSS)
GPIO8: R1.1, U2.10 (IO8)
I2C_PW: C1.1, C2.1, R1_PINH.2, R2_PINH.2, SENSOR2.2 (CSB), SENSOR2.6 (VDDIO), SENSOR2.8 (VDD), U2.17 (IO19)
INT_RTC: R1_PINH1.1, TP15.TP, U2.8 (IO0), U3.3 (SQW/!INT)
IO/BOOT: BOOT_BUTTON.3, BOOT_BUTTON.4, C6.1, R_BOOT.2, U2.15 (IO9)
IO/CHANGE: C10.1, CHANGE_BUTTON.3, CHANGE_BUTTON.4, R_CHANGE.2, U2.23 (IO15)
MISO: D12.2, J4.P7 (DAT0), R8.1, TP6.TP, U1.2 (DO(IO1)), U2.27 (IO2)
MOSI: D11.2, J1.14, J4.P3 (CMD), R7.1, TP7.TP, U1.5 (DI(IO0)), U2.7 (IO7)
unnamed: J2.A5, R2-USB1.2
unnamed: D7.1 (CATHODE), R_CAPACITOR.1
unnamed: J2.B5, R2-USB.1
unnamed: C1_BAT1.1, D2.1 (CATHODE), IC4.1 (VIN), IC4.3 (CE), Q1.2 (S)
unnamed: C4.1, D3.2 (A), D4.1 (K)
unnamed: R1_BAT.1, U5.1 (STAT)
unnamed: CHG_LED.C, R1_BAT.2
unnamed: R2_BAT.2, U5.5 (PROG)
unnamed: EPD_C12.1, J1.24
unnamed: EPD_C10.1, J1.22
unnamed: EPD_C8.1, J1.20
unnamed: EPD_C7.1, J1.19
unnamed: EPD_C6.1, J1.18
unnamed: EPD_C2.1, J1.5
unnamed: EPD_C1.1, J1.4
unnamed: C_DELAY.1, IC1.5 (CT)
PREVGH: D5.1 (K), EPD_C9.1, J1.21
PREVGL: D4.2 (A), EPD_C11.1, J1.23
RESE: J1.3, Q3.2 (S), R3.2
RESE': R2.2, R3.1, SJ1.2
RESET: C5.1, IC1.1 (VOUT), RESET_BUTTON.3, RESET_BUTTON.4, R_RESET.2, U2.3 (EN)
RTC_RST: U2.16 (IO18), U3.4 (!RST)
RX: TP2.TP, U2.24 (RXD0/GPIO17)
SCK: D10.2, J1.13, J4.P5 (CLK), R6.1, TP8.TP, U1.6 (CLK), U2.6 (IO6)
SCL: J3.4, R2_PINH.1, SENSOR2.4 (SCK), U2.20 (IO22), U3.16 (SCL), U4.7 (SCL)
SDA: J3.3, R1_PINH.1, SENSOR2.3 (SDI), U2.19 (IO21), U3.15 (SDA), U4.8 (SDA)
SRC: C4.2, D5.2 (A), L1.1, Q3.3 (D)
SS_SD: D8.2, J4.P2 (CD/DAT3), R10.1, U2.4 (IO4)
TX: TP1.TP, U2.25 (TXD0/GPIO16)
USB_D+: D1.4 (I/O2_2), U2.14 (IO13)
USB_D-: D1.6 (I/O1_2), U2.13 (IO12)
VBAT: C2_BAT.1, Q1.3 (D), TP3.TP, U4.2 (CELL), U4.3 (VDD), U5.3 (VBAT)
VBUS: C1_BAT.1, C4_USB.1, C5_USB.1, CHG_LED.A, D1.2 (GND), D2.2 (ANODE), PFMF.050.1.2, Q1.1 (G), R1_PWRUSB.2, TP14.TP, U5.4 (VIN)
VRTC: C8.1, C10_SUPERCAP.2, R_CAPACITOR.2, U3.14 (VBAT)
VUSB: J2.A4, J2.A9, J2.B4, J2.B9, PFMF.050.1.1

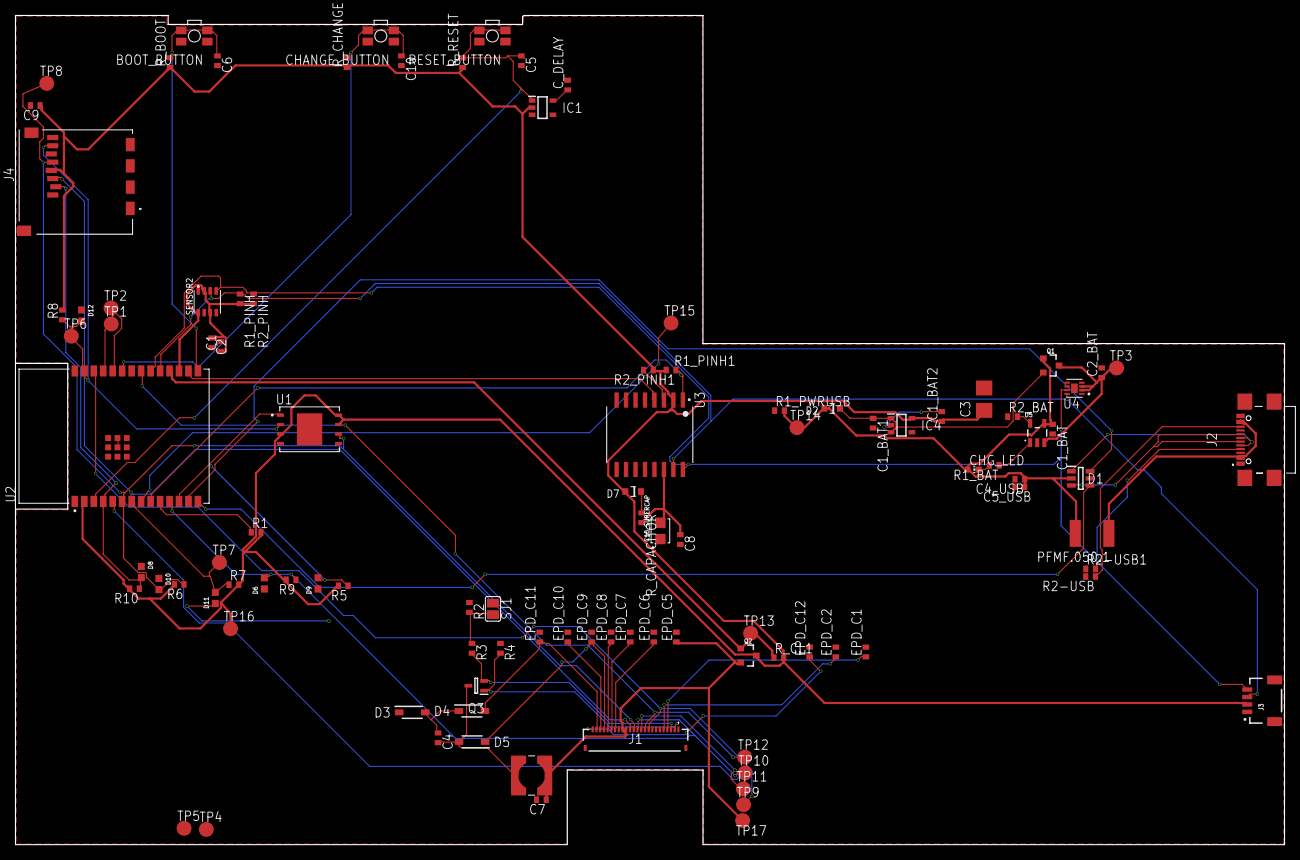
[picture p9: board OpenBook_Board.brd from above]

Board: 2 copper layers, 170.2 x 111.2 mm, 103 parts (0 on the bottom side), 55 nets.

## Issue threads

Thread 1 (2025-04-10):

Fix CHG_LED 3D Model

adrianariton, 2025-04-10:
## Issue

CHG_LED's 3D Model does not align with its pads.

## Reproduce

- open OpenBookDesign.step
- navigate to the dropdown and hide the lid `Body2`
- look to the left-bottom of the PCB to find the misplaced LED model

|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|
|:--:|
| *fig 1 (PCB)* |

|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|
|:--:|
| *fig 2 (left-bottom of the PCB) - CHG_LED* |

## Fixes and Suggestions

- [x] open the DeskAssistant library and right click to edit the 3d component and drag the component to align with te green rectangles in the scene (i.e. the pads) (see fig.3)
- [x] save and reload the library from the schema
- [x] push to 3d PCB - again

|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|
|:--:|
| *fig 3* |

monica-raluca, 2025-04-14:
Moved CHG Led in place in the library and pushed the new 3D PCB Design

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

Closed 2025-04-14.

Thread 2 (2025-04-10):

Improvements for CAD Models for Display & Battery

adrianariton, 2025-04-10:
# Issue

Models for the battery and the display can be improved

# Reproduce

> [!TIP]
> This is not a bug, but rather an improvement

## Fixes and Suggestions

- use the **Create -> Sketch -> Rectangle**  operation to create a rectangle which you can then redimension by using *Create -> Dimension* and clicking on the side you wish to redimension and input the new desired length for the side.
- use the **Create -> Sweep** tool to extrude a sketch along a path ([Check this tutorial out!](https://www.youtube.com/watch?v=QimeZSqS_sc)); this can help you create the 'holder' for the battery

- [x] improved battery
- [x] improved display
- [x] don't forget to right click on each of the two in the Openbook 3d file and hit the yellow triangle that says `update to latest version` to update the 3d models one modified

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

adrianariton, 2025-04-10:
Let's fix #1 first.

monica-raluca, 2025-04-16:
Fixed

Closed 2025-04-16.

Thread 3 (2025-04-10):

PCB Fix holes in GND plane

adrianariton, 2025-04-10:
## Issue

There are some holes in the GND plane (see with black)

## Reproduce

- open the [2d PCB](https://github.com/monica-raluca/OpenBook/tree/main/Hardware)

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

## Fixes and Suggestions

- use via stitching to fix both planes
- be careful to reroutes or wire breaks that can happen
- via stitching is really good for other parts of the PCB so this should feel relatively easy :)

monica-raluca, 2025-04-14:
**FIXED!**

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

Closed 2025-04-14.

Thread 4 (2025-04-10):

[Quick Fix] PCB Depth Fix

adrianariton, 2025-04-10:
- [x] Modify the PCB depth to 1mm
- [x] Make silkscreen more Readable in places after fixing #3

Closed 2025-04-16.

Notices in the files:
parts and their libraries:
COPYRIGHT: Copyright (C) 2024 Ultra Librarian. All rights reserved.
